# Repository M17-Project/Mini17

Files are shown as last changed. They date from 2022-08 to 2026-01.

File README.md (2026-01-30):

<div align='center'>










</div>

# Mini17
Mini17 - QRP M17 handheld.

# About
The first handheld to suport M17 was our own [TR-9](https://github.com/M17-Project/TR-9). Unfortunately, the design has a minor flaw in the RF part and is very hard to assemble. After that, we tried modifying various radios with different outcomes. This is our new device - the **Mini17**. It's built around the [CC1200](https://www.ti.com/product/CC1200) RF chip, which does great job at receiving and transmitting M17 signals. The power output is limited to 16dBm (40mW), so it's a QRP radio. The idea is to build a small radio first and then add RF power amplifier stage later. A *Proof of Concept*, if you will. The design could even be extended to a mobile rig in the future.

# Hardware
The RF chip used is CC1200, MCU is STM32F405RGT6. OLED display is the same as in [Module17](https://github.com/M17-Project/Module_17).

# Firmware
[OpenRTX](https://github.com/OpenRTX/OpenRTX) - the Linux of amateur radio!

# Structure
`/Hardware/KiCAD` contains two complete KiCAD projects, one for the mainboard and the other for the HMI<br>
`/MCU/Mini17.ioc` contains the pinout plan for an STM32F405RGT6 MCU (to be used with CubeIDE >=1.10.1)

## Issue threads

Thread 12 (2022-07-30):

H* mounting holes

sp5wwp, 2022-07-30:
Size M3 is too big, i suggest M2.

sp5wwp, 2022-07-31:
Fixed.

Closed 2022-07-31.

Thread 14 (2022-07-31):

Microphone-speaker "problem"

sp5wwp, 2022-07-31:
We need a different type of 3.5 and 2.5mm jack connectors to support both internal and external microphone/speaker. See the image below for details (that's a part of TYT MD-380 handheld transceiver).
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

JKI757, 2022-08-07:
Ok here's a 3.5mm that lines up with what you're looking for here I *think*.

https://www.digikey.com/en/products/detail/STX-3200-5NB/2092-STX-3200-5NB-ND/10246571

JKI757, 2022-08-07:
And this looks like a possible for the 2.5mm:

https://www.digikey.ca/en/products/detail/cui-devices/SJ2-25313D-SMT-TR/6619292

JKI757, 2022-08-07:
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

Use this one instead as it's available in lcsc per discussion in chat:

https://www.lcsc.com/product-detail/Audio-Connectors_BOOMELE-Boom-Precision-Elec-PJ-307C_C16684.html

sp5wwp, 2022-08-08:
Schematic fixed.

Closed 2022-08-08.

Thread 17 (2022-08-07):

SD card holder footprint

sp5wwp, 2022-08-07:
Set it to the correct one.

sp5wwp, 2022-08-07:
List:
https://lcsc.com/products/SD-Card-Connectors_11334.html

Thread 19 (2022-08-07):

Missing DFU mode

sp5wwp, 2022-08-07:
Set `BOOTn` pins in the way so that the device enters DFU mode much like the Module17 does - one of the keyboard buttons has to be kept pressed at power-up.

sp5wwp, 2022-08-16:
Added.

Closed 2022-08-16.

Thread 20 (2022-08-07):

Lacking R_EXT for the 8 MHz crystal oscillator

sp5wwp, 2022-08-07:
Add a place for a series resistor at `XTAL_1`, pin #24, make it 0R for now.

Closed 2022-08-07.

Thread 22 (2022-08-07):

Volume potentiometer

sp5wwp, 2022-08-07:
Are we going to use the same pot as in Module17? With an ON/OFF switch.

sp5wwp, 2022-08-08:
Need the PN of the pot used in Module17.

sp5wwp, 2022-08-16:
One of the `ACZ11BRXE` family of pots.

sp5wwp, 2022-08-18:
> This is the potentiometer we used for Module17: https://www.digikey.com/en/products/detail/bourns-inc/PTR901-2015K-B203/3780802

Is the footprint correctly set in the schematic?

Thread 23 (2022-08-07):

Add a rotary encoder with a push button

sp5wwp, 2022-08-07:

JKI757, 2022-08-07:
this one?

https://www.lcsc.com/product-detail/Rotary-Encoders_BOURNS-PEC11R-4015F-S0024_C143789.html

sp5wwp, 2022-08-07:
We need one that's 90*.

JKI757, 2022-08-07:
ah yes, good point.

JKI757, 2022-08-07:
LCSC isn't coming back with something that makes sense at least at first glance, but I did find one at digikey that might work:

https://www.digikey.com/en/products/detail/cts-electrocomponents/11CEY25F243B/13152999

sp5wwp, 2022-08-08:
I believe JLCPCB can source parts from Mouser and Avnet. Lets try there.

Yep:
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

sp5wwp, 2022-08-09:
> LCSC isn't coming back with something that makes sense at least at first glance, but I did find one at digikey that might work:
>
> https://www.digikey.com/en/products/detail/cts-electrocomponents/11CEY25F243B/13152999

I believe this one might be too big to fit between two boards.

sp5wwp, 2022-08-16:
One of the `ACZ11BRXE` family of encoders?

JKI757, 2022-08-17:
This seems to be the only one with the right mounting option available:

https://www.mouser.com/ProductDetail/CUI-Devices/ACZ11BR4E-15FA1-20C?qs=WyjlAZoYn521vRzc3WQA5g%3D%3D

JKI757, 2022-08-17:
ok that's added to the schematic and repo, will be in the PR I send up in a bit.

xfce, 2023-03-07:
hi all
        I am a ham in China, also a hardware engineer and familiar with JLC, my callsign is bi4wms, maybe I can give some help

sp5wwp, 2023-03-07:
Mini17 isn't under development right now, but [OpenHT](https://github.com/M17-Project/OpenHT-hw) is.

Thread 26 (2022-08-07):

RGB LED

sp5wwp, 2022-08-07:
How about using an RGB LED instead of 3 separate ones?

JKI757, 2022-08-07:
I like it.  Nice one shot LED at the top of the radio that can do 4 or 5 different colors without too much trouble would be nice.

sp5wwp, 2022-08-08:
Added in #30

Closed 2022-08-08.

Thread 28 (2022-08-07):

Should we use an open-source alternative to CubeIDE?

uranuspucksaxophone, 2022-08-07:

JKI757, 2022-08-07:
CubeIDE is an ST configured version of Eclipse packaged up with GDB.

CubeMX simply provides configuration info for the MCU.  There's no requirement to use it, and the existing codebases people anticipate putting on here as far as I know aren't based on it. Even if they are, I don't think it matters.

The use of CubeMX/CubeIDE doesn't "infect" anything with regard to licensing, at least not that I'm aware of.

The presence of the .ioc file doesn't place any constraints on anyone -- I'm using CubeMX just a tool to assist in validating schematic design and I'll probably create some test firmware with it at some point as well.  It saves a ton of time in figuring out what pins are compatible with what signals and where to put them for better routing on the PCB as well.

IOW don't read too much into the existence of an ioc file -- it's just a tool.

sp5wwp, 2022-08-07:
This file is only used for setting pin configuration.

Closed 2022-08-07.

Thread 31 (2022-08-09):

Separate boards

sp5wwp, 2022-08-09:
Put all interface (microphone, speaker, keyboard, PTT/F1/F2 buttons, rotary encoder, Kenwood connector, OLED display) on a separate board.

JKI757, 2022-08-10:
Interesting way of looking at it I guess -- was looking at the TYT design, they've got the microphone, keypad, and display on a separate board, but all the other interface components are on the mainboard.

I think we need someone to create a physical design of some sort, because that is going to drive these kinds of discussions.  I was even thinking as I worked on the board tonight, why not just use the tyt front panel as it is?   essentially we'd just be replacing the mainboard, we could even re-use the volume, encoder (which I'm still not finding one that I think will work), PTT buttons, etc.

LongHairedHacker, 2022-08-11:
I don't think creating a replacement mainboard for another device is the best approach here.
It sure is tempting idea you get an enclosure, a battery, display and everything in nice form factor (also chargers and other accessories...)
However I already had some trouble getting a MD380 to mod for M17 for a reasonable price.
So it might not be the best idea to tie peoples ability to build a mini17 to the availability of some existing radio.
Also that doesn't really feel open hardware to me.

In my opinion it might be a little to early to think about physical design.
I'd much rather prefer to to have two stacked rectangular boards in the first iteration.
It shouldn't be to hard to come up with an enclosure for something like that using a lasercutter or a 3d printer.

Once the design verified to work, we can talk designing a nice polished enclosure and make the boards fit in that.

JKI757, 2022-08-11:
You absolutely have to have some physical design to line up your board design to, otherwise you are building a dev board, you might as well totally ignore form factor, and you need to plan to completely redesign it when you decide you want to build a handheld radio -- and there's no point in doing any board at all if you're going to do that, you just buy the manufacturer supplied dev board (https://www.ti.com/tool/CC1200DK) and focus your development efforts on the software.

We've decided to go a different way with this, but MD380s are 130 bucks on Amazon in apparently unlimited quantity, and they're even cheaper used on eBay.  I still think that simply designing a drop-in main board replacement for that radio (or the 390 or any other radio already in the supply chain) would be far superior to other approaches for all the reasons you list above.

sp5wwp, 2022-08-15:
The design is now split into 2.

Closed 2022-08-15.

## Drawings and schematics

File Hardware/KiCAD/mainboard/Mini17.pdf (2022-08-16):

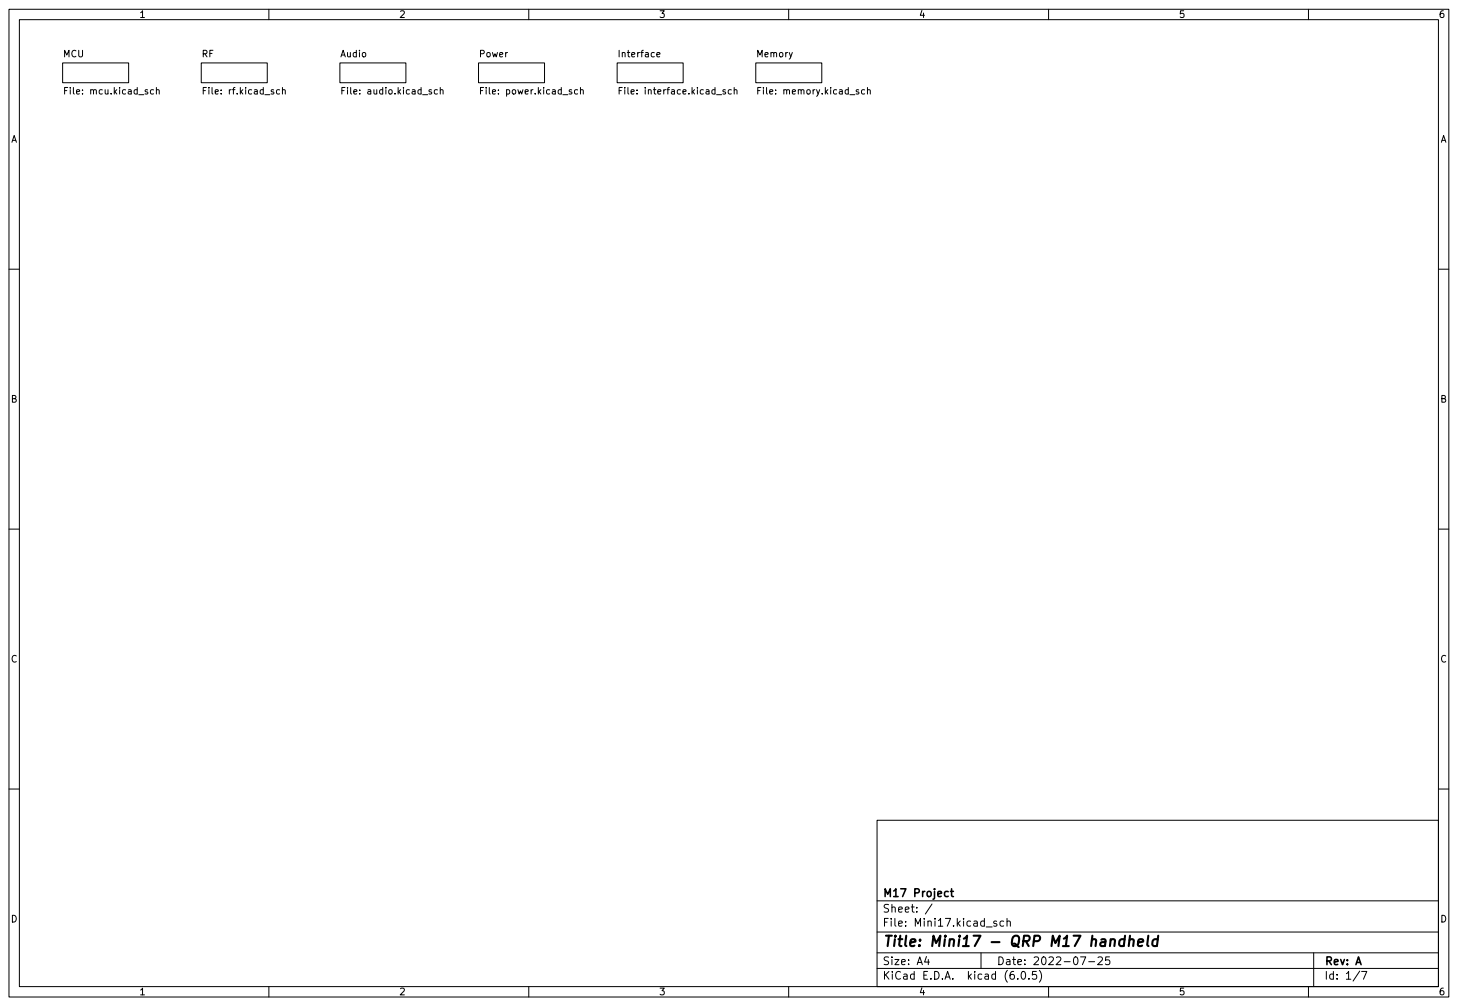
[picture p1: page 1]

Audio File: audio.kicad_sch MCU

Id: 1/7 Title: Mini17 - QRP M17 handheld

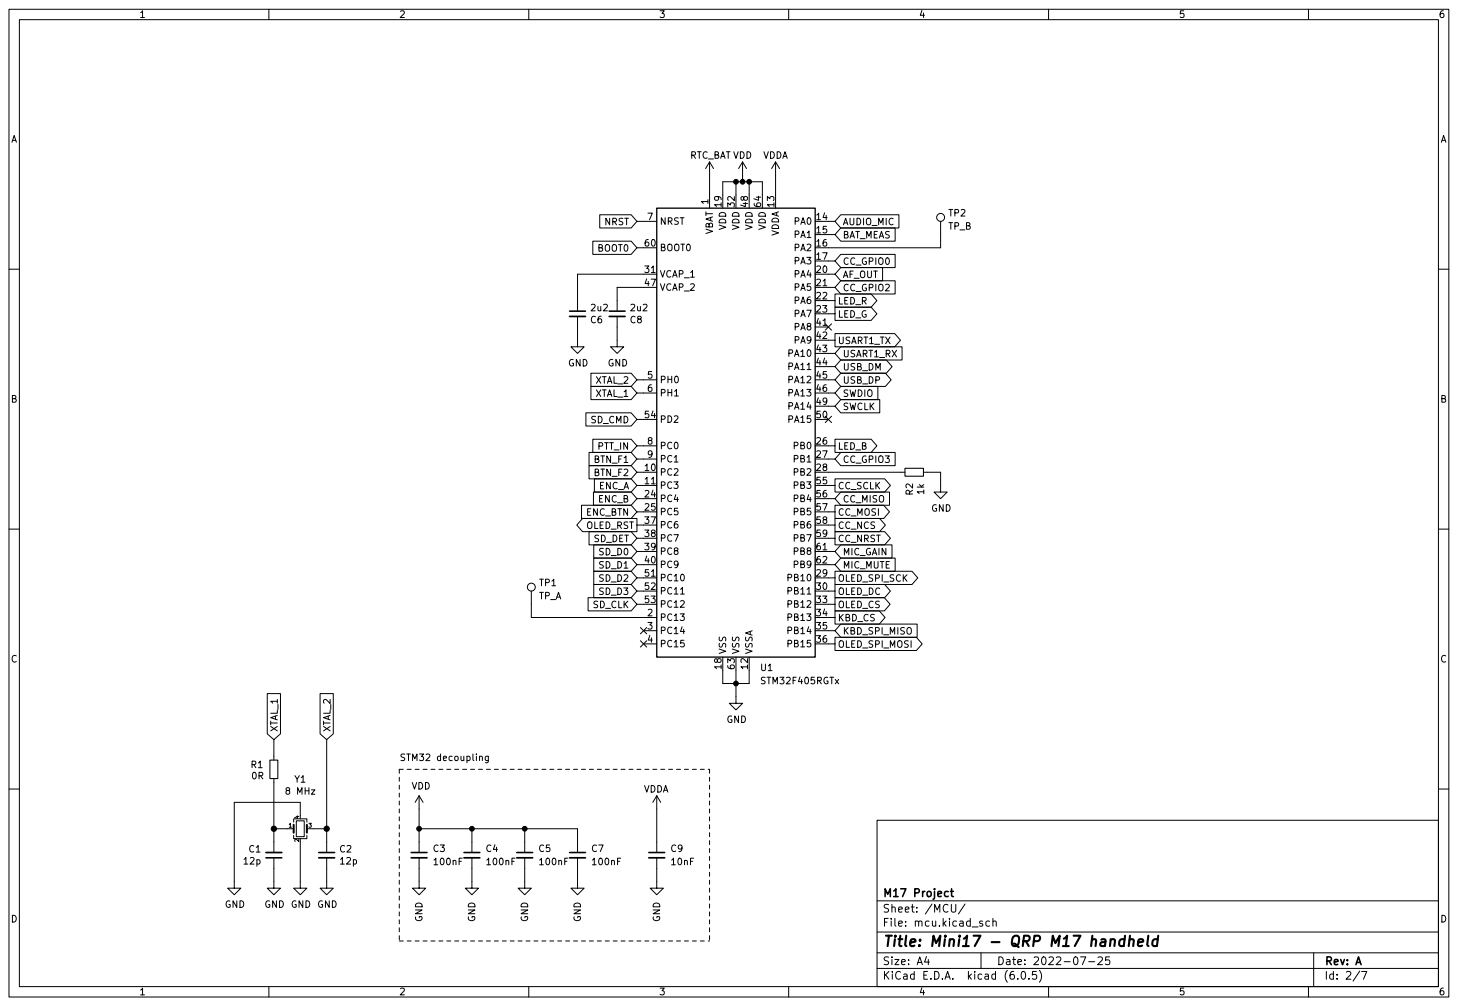
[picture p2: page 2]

File: mcu.kicad_sch Sheet: /MCU/ M17 Project GND

Id: 2/7 Title: Mini17 - QRP M17 handheld

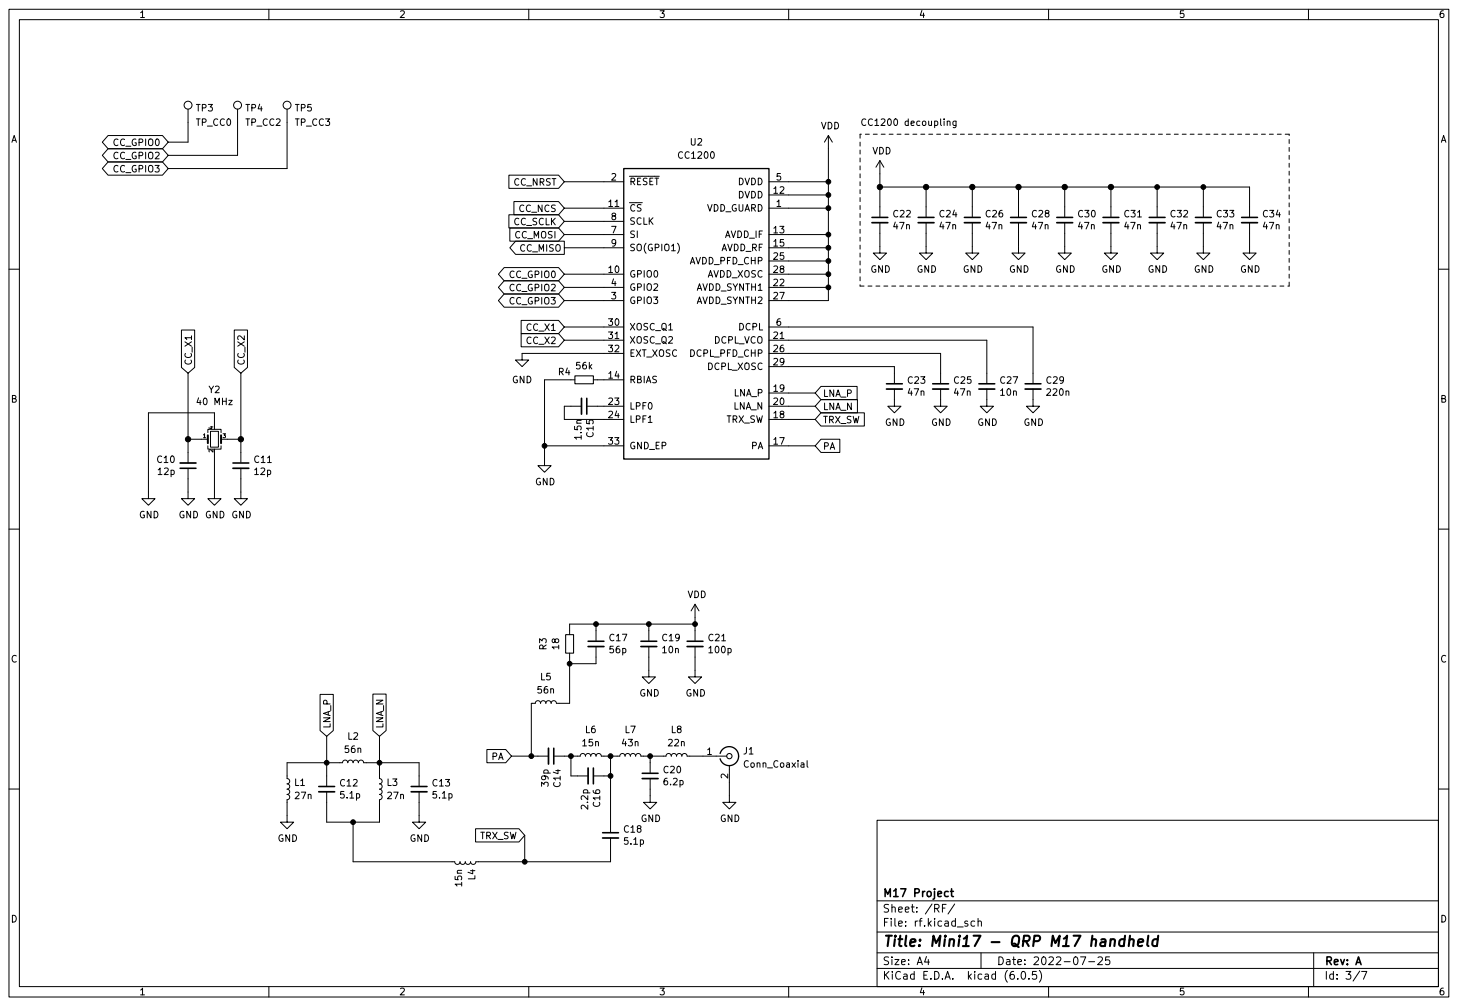
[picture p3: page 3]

Id: 3/7 Title: Mini17 - QRP M17 handheld

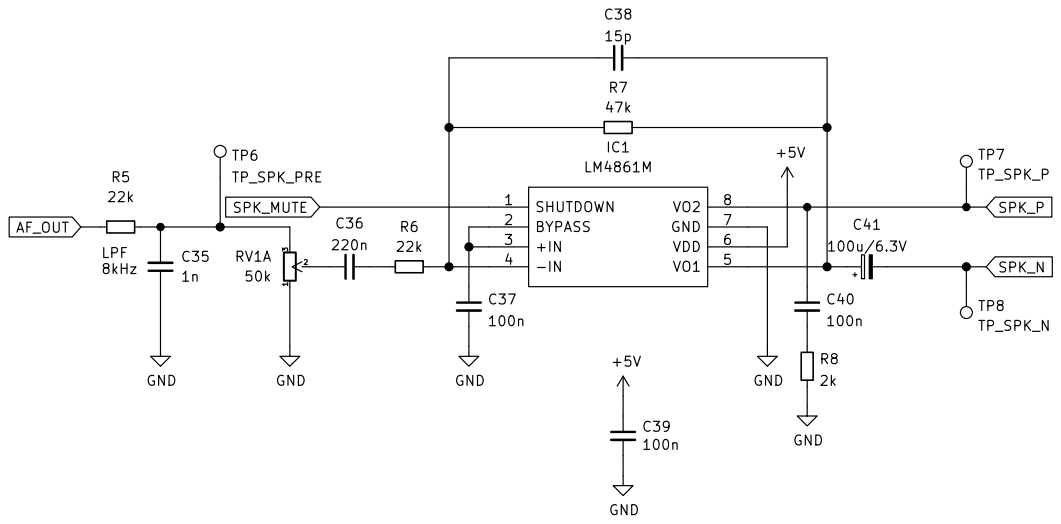
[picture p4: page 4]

File: audio.kicad_sch Sheet: /Audio/ M17 Project

Id: 4/7 Title: Mini17 - QRP M17 handheld

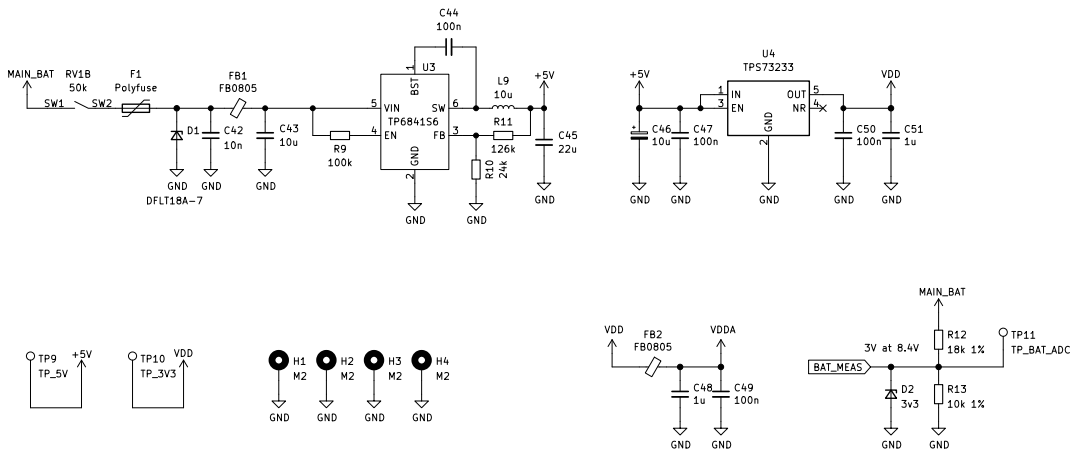
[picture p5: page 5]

2 EN 3 NR 4 OUT 5 U4 TPS73233 H2 M2 GND GND

2 FB 3 EN 4 VIN 5 SW 6 U3 TP6841S6H4 M2 GND

Id: 5/7 Title: Mini17 - QRP M17 handheld

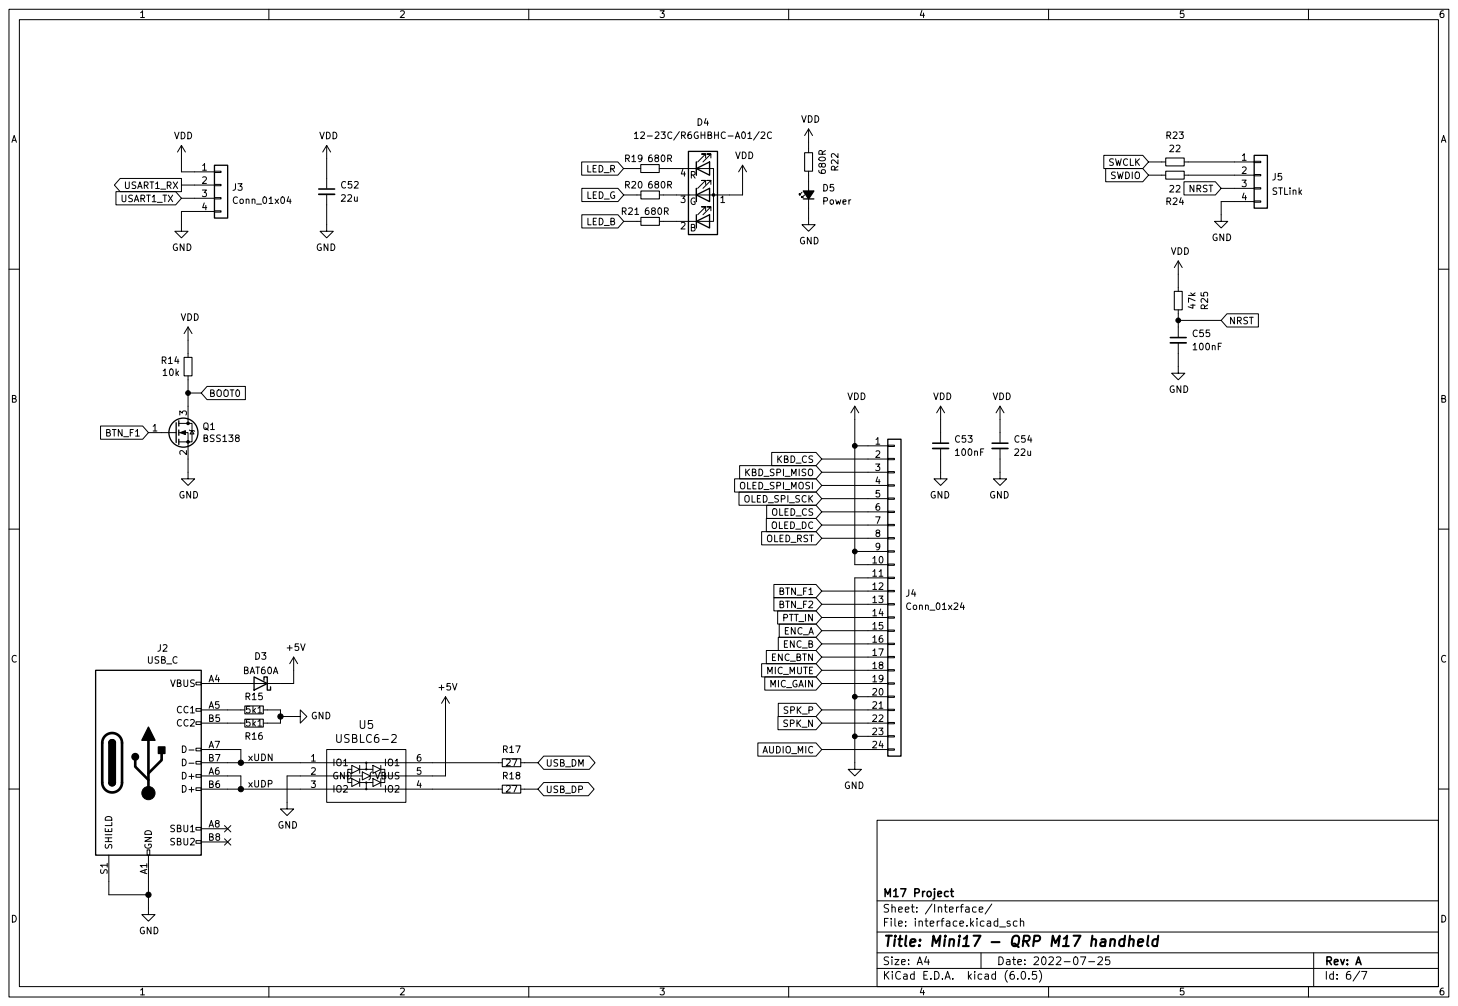
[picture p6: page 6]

File: interface.kicad_sch Sheet: /Interface/ M17 Project GND

Id: 6/7 Title: Mini17 - QRP M17 handheld

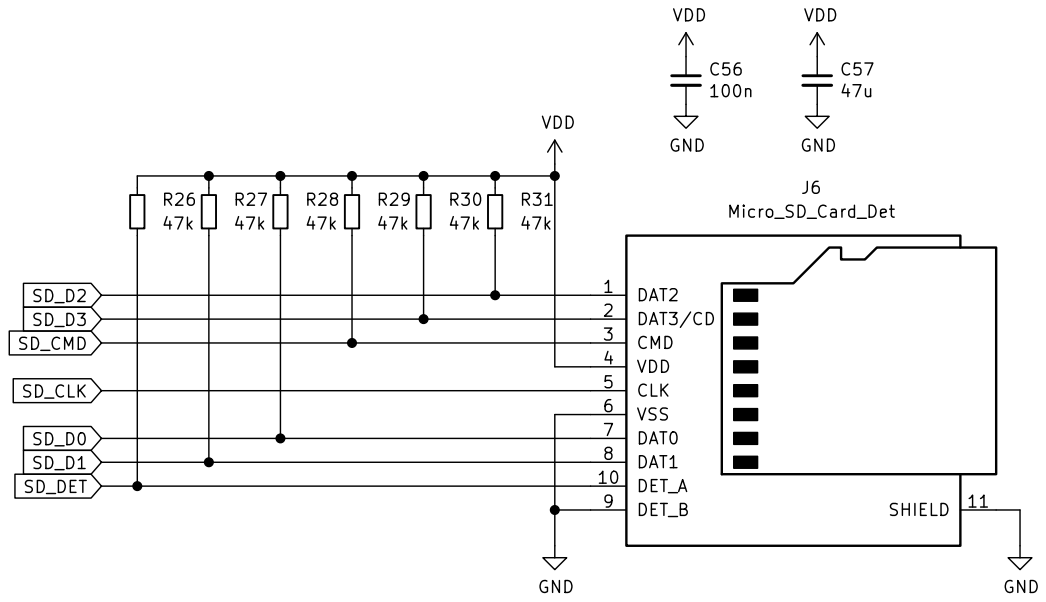
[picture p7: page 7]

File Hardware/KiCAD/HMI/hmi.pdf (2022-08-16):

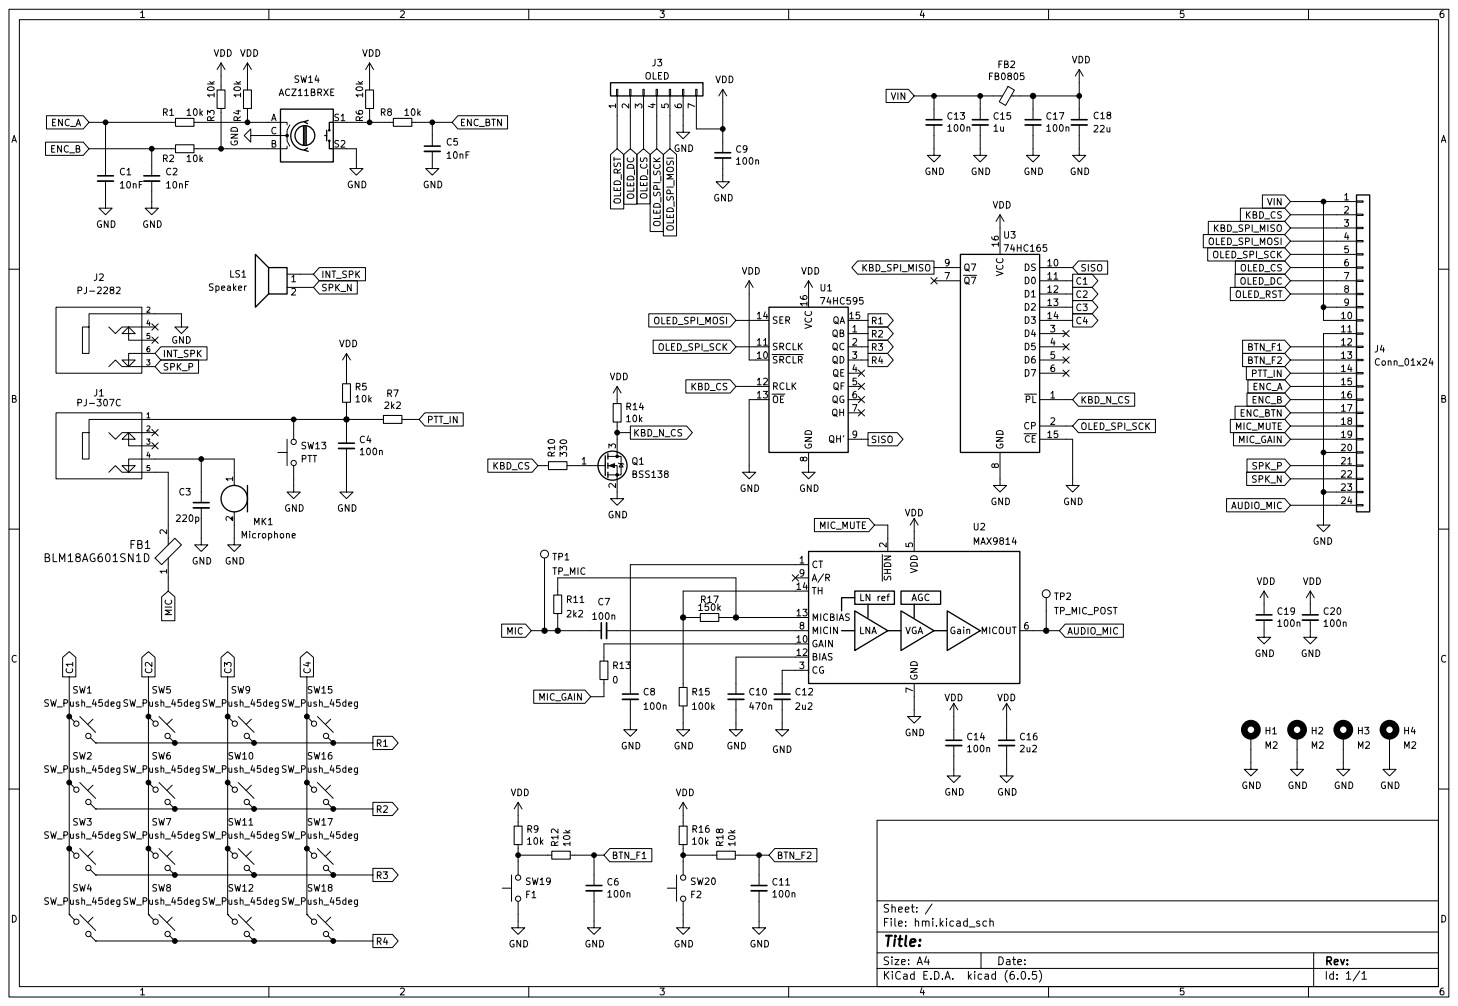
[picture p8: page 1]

7 MICIN 8 A/R 9 U2MAX9814 VDD GND GND GND

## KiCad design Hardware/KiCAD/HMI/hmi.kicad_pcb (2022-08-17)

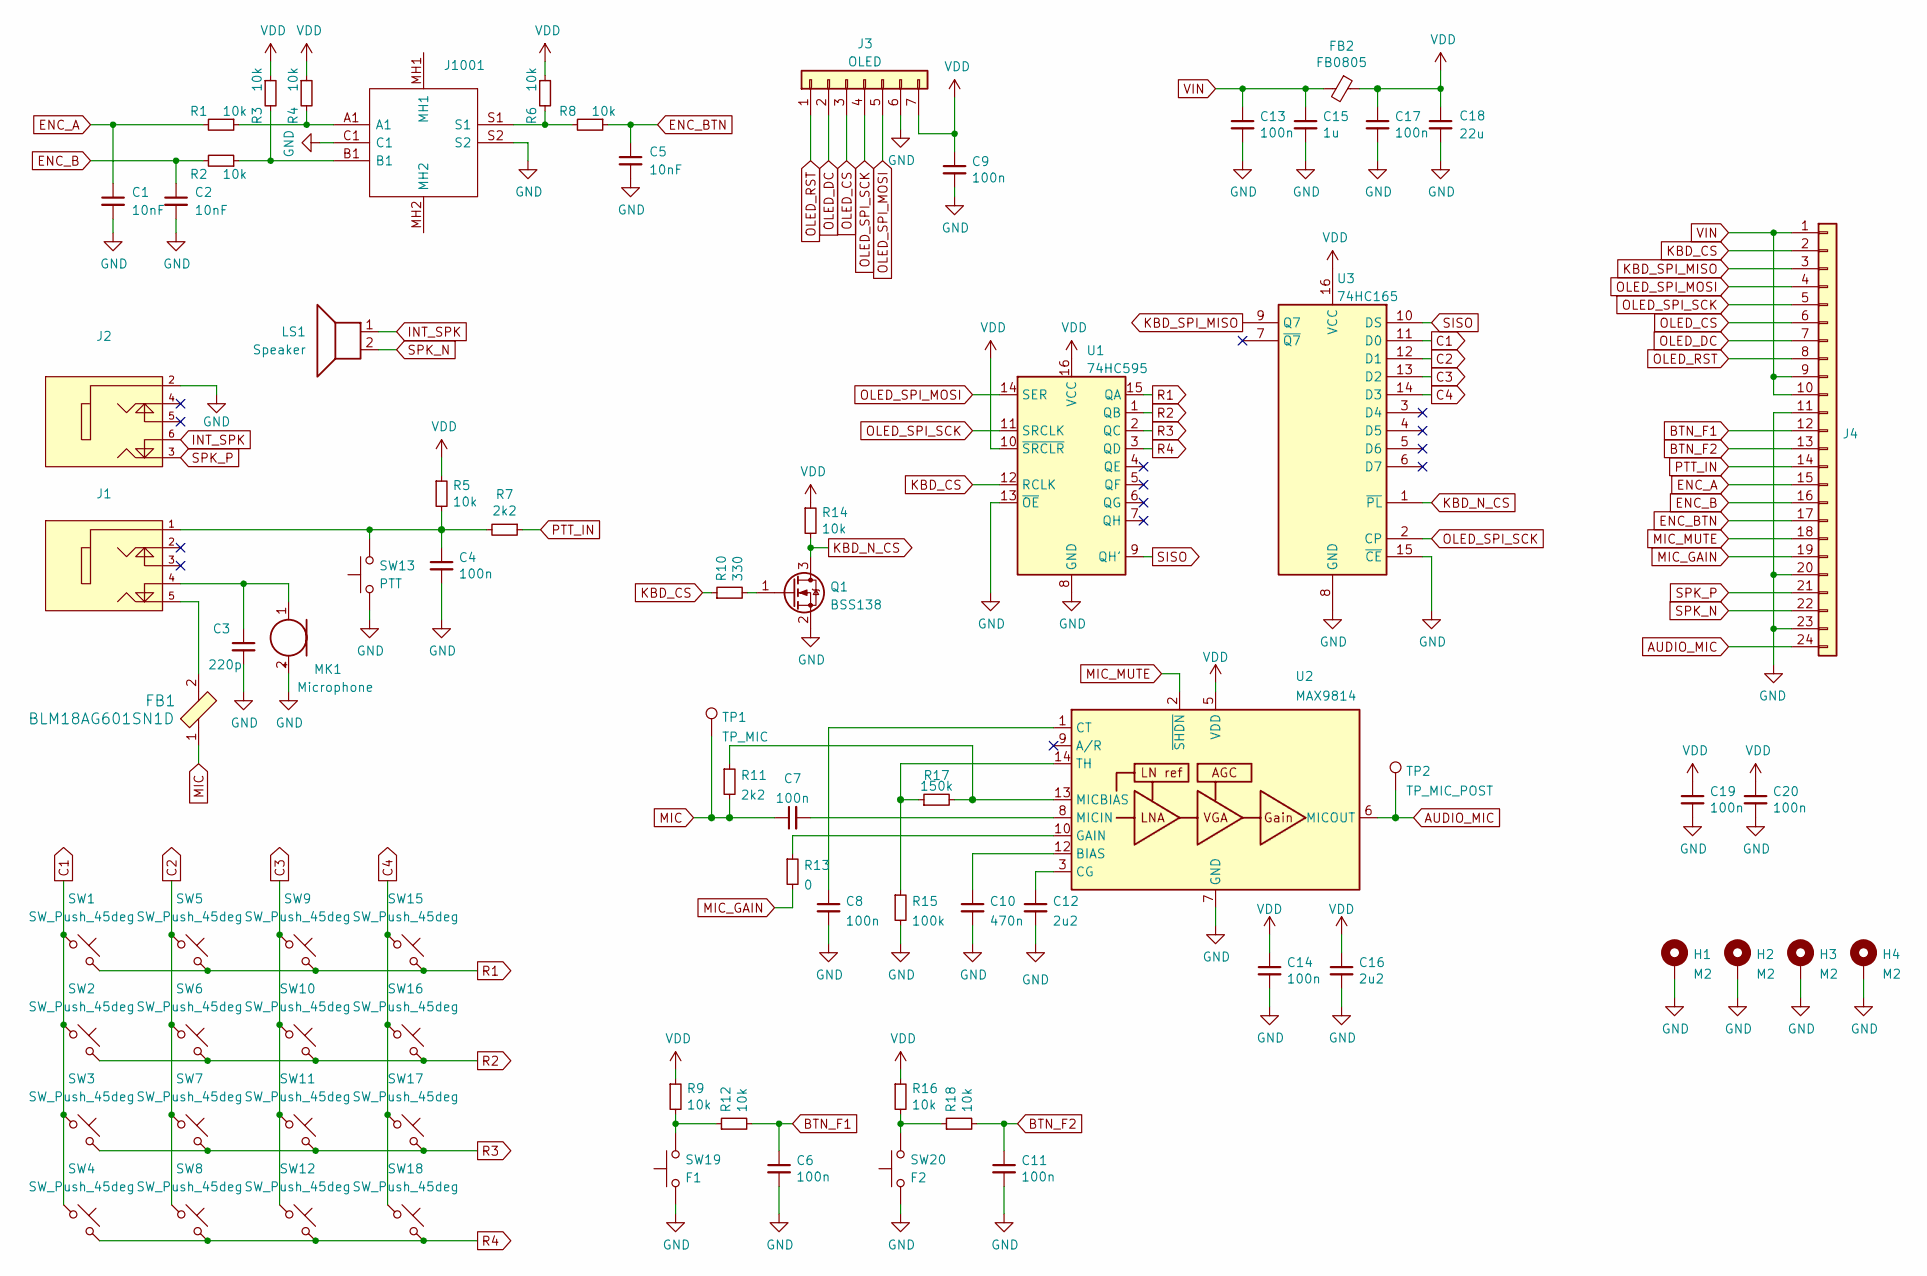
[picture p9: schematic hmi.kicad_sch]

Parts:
C1, C2, C5: 10nF; C_0402_1005Metric
C3: 220p; C_0402_1005Metric
C4, C6, C7, C8, C9, C11, C13, C14, C17, C19, C20: 100n; C_0402_1005Metric
C10: 470n; C_0402_1005Metric
C12, C16: 2u2; C_0402_1005Metric
C15: 1u; C_0402_1005Metric
C18: 22u; C_1210_3225Metric
FB1: BLM18AG601SN1D; 0603; MPN BLM18AG601SN1D; Digi-Key_PN 490-1014-1-ND
FB2: FB0805; Fuse_0805_2012Metric
H1, H2, H3, H4: M2; MountingHole_2.2mm_M2_DIN965_Pad
J1, J2, J4: (no value)
J3: OLED; PinHeader_1x07_P2.54mm_Vertical
J1001: Manufacturer_Part_Number ACZ11BR4E-15FA1-20C; Mouser Part Number 490-ACZ11E15FA120C
LS1: Speaker; PinHeader_1x02_P2.54mm_Vertical
MK1: Microphone
Q1: BSS138; SOT-23
R1, R2, R3, R4, R5, R6, R8, R9, R12, R14, R16, R18: 10k; R_0402_1005Metric
R7, R11: 2k2; R_0402_1005Metric
R10: 330; R_0402_1005Metric
R13: 0; R_0402_1005Metric
R15: 100k; R_0402_1005Metric
R17: 150k; R_0402_1005Metric
SW1, SW2, SW3, SW4, SW5, SW6, SW7, SW8, SW9, SW10, SW11, SW12, SW15, SW16, SW17, SW18: SW_Push_45deg; SW_Push_1P1T_NO_CK_KMR2
SW13: PTT; SW_Tactile_SPST_Angled_PTS645Vx31-2LFS
SW19: F1; SW_Tactile_SPST_Angled_PTS645Vx31-2LFS
SW20: F2; SW_Tactile_SPST_Angled_PTS645Vx31-2LFS
TP1: TP_MIC; TestPoint_Pad_D1.0mm
TP2: TP_MIC_POST; TestPoint_Pad_D1.0mm
U1: 74HC595; SOIC-16_3.9x9.9mm_P1.27mm
U2: MAX9814; DFN-14-1EP_3x3mm_P0.4mm_EP1.78x2.35mm
U3: 74HC165; SOIC-16_3.9x9.9mm_P1.27mm

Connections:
AUDIO_MIC: J4.24, TP2.1, U2.6 (MICOUT)
BTN_F1: C6.1, J4.12, R12.2
BTN_F2: C11.1, J4.13, R18.2
C1: SW1.1, SW2.1, SW3.1, SW4.1, U3.11 (D0)
C2: SW5.1, SW6.1, SW7.1, SW8.1, U3.12 (D1)
C3: SW9.1, SW10.1, SW11.1, SW12.1, U3.13 (D2)
C4: SW15.1, SW16.1, SW17.1, SW18.1, U3.14 (D3)
ENC_A: C1.1, J4.15, R1.2
ENC_B: C2.1, J4.16, R2.2
ENC_BTN: C5.1, J4.17, R8.1
GND: C1.2, C2.2, C3.2, C4.2, C5.2, C6.2, C8.2, C9.2, C10.2, C11.2, C12.2, C13.2, C14.2, C15.2, C16.2, C17.2, C18.2, C19.2, C20.2, H1.1, H2.1, H3.1, H4.1, J2.2, J3.6, J4.11, J4.20, J4.23, J1001.C1, J1001.S2, MK1.2 (+), Q1.2 (S), R15.2, SW13.1, SW19.1, SW20.1, U1.8 (GND), U1.13 (~OE), U2.4 (GND), U2.7 (GND), U2.11 (GND), U2.15 (GND), U3.8 (GND), U3.15 (~CE)
INT_SPK: J2.6, LS1.1
KBD_CS: J4.2, R10.1, U1.12 (RCLK)
KBD_N_CS: Q1.3 (D), R14.2, U3.1 (~PL)
KBD_SPI_MISO: J4.3, U3.9 (Q7)
MIC: C7.1, FB1.1, R11.2, TP1.1
MIC_GAIN: J4.19, R13.2
MIC_MUTE: J4.18, U2.2 (~SHDN)
unnamed: C3.1, J1.4, MK1.1 (-)
unnamed: C4.1, J1.1, R5.2, R7.2, SW13.2
unnamed: C7.2, U2.8 (MICIN)
unnamed: C8.1, U2.1 (CT)
unnamed: C10.1, U2.12 (BIAS)
unnamed: C12.1, U2.3 (CG)
unnamed: FB1.2, J1.5
unnamed: Q1.1 (G), R10.2
unnamed: J1001.A1, R1.1, R4.2
unnamed: J1001.B1, R2.1, R3.2
unnamed: J1001.S1, R6.2, R8.2
unnamed: R11.1, R17.2, U2.13 (MICBIAS)
unnamed: R9.2, R12.1, SW19.2
unnamed: R13.1, U2.10 (GAIN)
unnamed: R15.1, R17.1, U2.14 (TH)
unnamed: R16.2, R18.1, SW20.2
OLED_CS: J3.3, J4.6
OLED_DC: J3.2, J4.7
OLED_RST: J3.1, J4.8
OLED_SPI_MOSI: J3.5, J4.4, U1.14 (SER)
OLED_SPI_SCK: J3.4, J4.5, U1.11 (SRCLK), U3.2 (CP)
PTT_IN: J4.14, R7.1
R1: SW1.2, SW5.2, SW9.2, SW15.2, U1.15 (QA)
R2: SW2.2, SW6.2, SW10.2, SW16.2, U1.1 (QB)
R3: SW3.2, SW7.2, SW11.2, SW17.2, U1.2 (QC)
R4: SW4.2, SW8.2, SW12.2, SW18.2, U1.3 (QD)
SISO: U1.9 (QH'), U3.10 (DS)
SPK_N: J4.22, LS1.2
SPK_P: J2.3, J4.21
VDD: C9.1, C14.1, C16.1, C17.1, C18.1, C19.1, C20.1, FB2.1, J3.7, R3.1, R4.1, R5.1, R6.1, R9.1, R14.1, R16.1, U1.10 (~SRCLR), U1.16 (VCC), U2.5 (VDD), U3.16 (VCC)
VIN: C13.1, C15.1, FB2.2, J4.1, J4.9, J4.10

Board: 2 copper layers, 73 parts (0 on the bottom side), 45 nets, no tracks yet.

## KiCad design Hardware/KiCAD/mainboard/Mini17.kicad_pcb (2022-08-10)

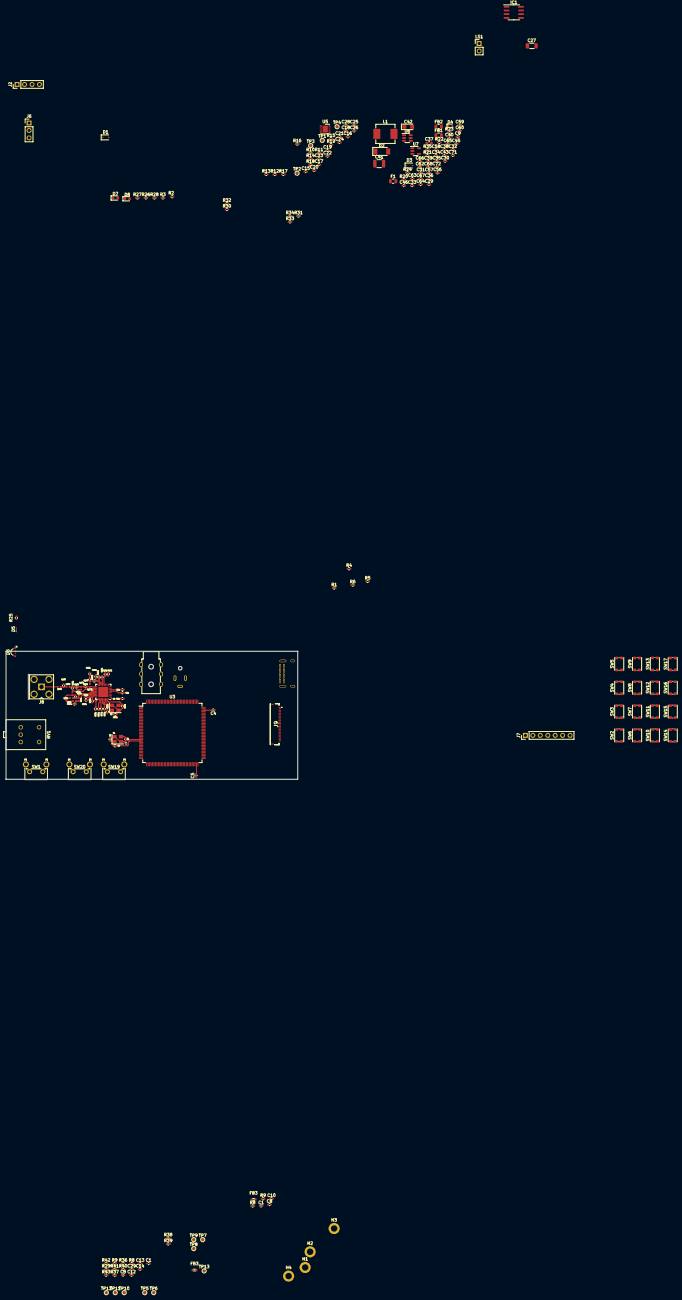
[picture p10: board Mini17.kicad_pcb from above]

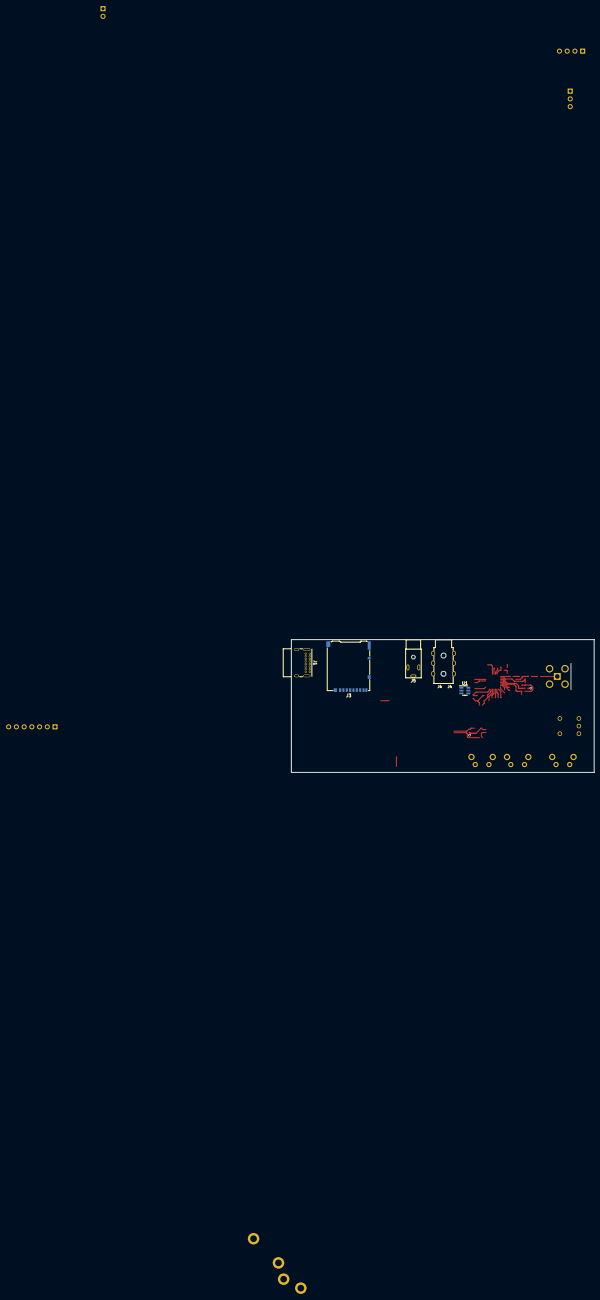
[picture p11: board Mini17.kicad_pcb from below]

Board: 4 copper layers, 99.6 x 43.7 mm, 209 parts (5 on the bottom side), 123 nets.

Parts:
C1, C23, C61: 220n; C_0402_1005Metric
C1#2, C8#2, C12, C68: 10nF; C_0402_1005Metric
C2, C3, C301, C311: 12p; C_0402_1005Metric
C4, C5, C19, C21: 2u2; C_0402_1005Metric
C8: 4.7u; C_0402_1005Metric
C9, C13, C56, C57, C58, C59, C60, C62, C63, C64, C65, C66, C67: 100nF; C_0402_1005Metric
C10: 220p; C_0402_1005Metric
C11, C29#2, C30, C31, C32, C33, C34, C36, C51, C71, C72, C121, C131, C151, C221, C251, C261, C271, C281, C291: 47n; C_0402_1005Metric
C14, C15, C16, C18, C20, C24, C26, C28, C29, C38, C40, C43, C45: 100n; C_0402_1005Metric
C17: 470n; C_0402_1005Metric
C22: 1n; C_0402_1005Metric
C25: 15p; C_0402_1005Metric
C27: 100u/6.3V; C_1206_3216Metric
C35, C171, C211: 10n; C_0402_1005Metric
C37: 10u; C_0603_1608Metric
C39, C46: 1u; C_0402_1005Metric
C41: 22u; C_1210_3225Metric
C42: 10u; CP_EIA-3216-18_Kemet-A
C172: 100p; C_0402_1005Metric
C173: 56p; C_0402_1005Metric
C174: 39p; C_0402_1005Metric
C175: 6.2p; C_0402_1005Metric
C176: 2.2p; C_0402_1005Metric
C181, C191, C201: 5.1p; C_0402_1005Metric
C231: 1.5n; C_0402_1005Metric
D1, D3: BAT60A; D_SOD-323
D2: DFLT18A-7; D_SOD-128
D4: 3v3; D_SOD-523
D5: Power; D_0201_0603Metric
D6: 12-23C/R6GHBHC-A01/2C; LED_RGB_Everlight_EASV3015RGBA0_Horizontal
D7: Sync; D_0603_1608Metric
D8: Error; D_0603_1608Metric
F1: Polyfuse; Fuse_0805_2012Metric
FB1, FB2: FB0805; Fuse_0805_2012Metric
FB3, FB3#2: BLM18AG601SN1D; 0603
H1, H2, H3, H4: M2; MountingHole_2.2mm_M2_DIN965_Pad
IC1: LM4861M; SOIC-8_3.9x4.9mm_P1.27mm
J1: USB_C; USB_C_Receptacle_GCT_USB4085
J2: STLink; PinHeader_1x04_P2.54mm_Vertical
J3: Micro_SD_Card_Det; microSD_HC_Hirose_DM3AT-SF-PEJM5
J4: Kenwood-3.5; PJ-3136-B
J5: Kenwood-2.5; PJ-211A
J6: UART; PinHeader_1x03_P2.54mm_Vertical
J7: OLED; PinHeader_1x07_P2.54mm_Vertical
J8: Conn_Coaxial; SMA_Amphenol_901-143_Horizontal
J9: Front Panel Connector; FH19SC24S05SH09
L1: 10u; L_Vishay_IHLP-2525
L171, L191: 56n; L_0402_1005Metric
L172, L193: 15n; L_0402_1005Metric
L173: 43n; L_0402_1005Metric
L174: 22n; L_0402_1005Metric
L192, L201: 27n; L_0402_1005Metric
LS1: Speaker; PinHeader_1x02_P2.54mm_Vertical
R1, R2: 5k1; R_0402_1005Metric
R3, R4: 22; R_0402_1005Metric
R5, R6: 27; R_0402_1005Metric
R7: 0R; R_0402_1005Metric
R8, R9#2, R14, R29, R36, R37, R38, R40, R41, R42, R43: 10k; R_0402_1005Metric
R8#2: 470; R_0402_1005Metric
R9: 1k8; R_0402_1005Metric
R10, R15: 2k2; R_0402_1005Metric
R11: 0; R_0402_1005Metric
R12, R20: 100k; R_0402_1005Metric
R13: 150k; R_0402_1005Metric
R16, R17: 22k; R_0402_1005Metric
R18, R30, R31, R32, R33, R34, R39: 47k; R_0402_1005Metric
R19: 2k; R_0402_1005Metric
R21: 24k; R_0402_1005Metric
R22: 126k; R_0402_1005Metric
R23: 18k 1%; R_0402_1005Metric
R24: 10k 1%; R_0402_1005Metric
R25, R26, R27, R28: 680R; R_0402_1005Metric
R35: 1k; R_0402_1005Metric
R141: 56k; R_0402_1005Metric
R171: 18; R_0402_1005Metric
RV1: 50k; PTR901
SW1: PTT; SW_Tactile_SPST_Angled_PTS645Vx31-2LFS
SW2, SW3, SW4, SW5, SW6, SW7, SW8, SW9, SW10, SW11, SW12, SW13, SW14, SW15, SW16, SW17: SW_Push_45deg; SW_Push_1P1T_NO_CK_KMR2
SW19: F1; SW_Tactile_SPST_Angled_PTS645Vx31-2LFS
SW20: F2; SW_Tactile_SPST_Angled_PTS645Vx31-2LFS
TP1: TP_MIC; TestPoint_Pad_D1.0mm
TP2: TP_MIC_POST; TestPoint_Pad_D1.0mm
TP3: TP_SPK_PRE; TestPoint_Pad_D1.0mm
TP4: TP_SPK_N; TestPoint_Pad_D1.0mm
TP5: TP_B; TestPoint_Pad_D1.0mm
TP6: TP_A; TestPoint_Pad_D1.0mm
TP7: TP_CC0; TestPoint_Pad_D1.0mm
TP8: TP_CC2; TestPoint_Pad_D1.0mm
TP9: TP_CC3; TestPoint_Pad_D1.0mm
TP10: TP_5V; TestPoint_Pad_D1.0mm
TP11: TP_3V3; TestPoint_Pad_D1.0mm
TP12: TP_BAT_ADC; TestPoint_Pad_D1.0mm
TP13: TP_SPK_P; TestPoint_Pad_D1.0mm
U1: USBLC6-2; SOT-23-6
U3: STM32F427ZGTx; LQFP-144_20x20mm_P0.5mm
U4: CC1200; QFN-32-1EP_5x5mm_P0.5mm_EP3.45x3.45mm
U5: MAX9814; DFN-14-1EP_3x3mm_P0.4mm_EP1.78x2.35mm
U6: TP6841S6; SOT-23-6
U7: TPS73233; SOT-23-5
Y1: 8 MHz; Crystal_SMD_3225-4Pin_3.2x2.5mm
Y3: 40 MHz; Crystal_SMD_3225-4Pin_3.2x2.5mm

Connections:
+5V: C28.1, C41.1, C42.1, C43.1, D1.1 (K), IC1.6 (VDD), J4.T, L1.1, R8#2.1, R22.2, TP10.1, U1.5 (VBUS), U7.1 (IN), U7.3 (EN)
/Interface/xUDN: J1.A7 (D-), J1.B7 (D-), U1.1 (IO1)
/Interface/xUDP: J1.A6 (D+), J1.B6 (D+), U1.3 (IO2)
AF_OUT: R16.1, U3.40 (PA4)
AUDIO_MIC: TP2.1, U3.34 (PA0), U5.6 (MICOUT)
BAT_MEAS: D4.1 (K), R23.2, R24.1, TP12.1, U3.35 (PA1)
BOOT0: C29.1, R43.2, U3.22 (PF10), U3.138 (BOOT0)
BTN_F1: C14.1, R41.2, U3.26 (PC0)
C1: J9.5, SW2.1, SW3.1, SW4.1, SW5.1, U3.57 (PG1)
C2: J9.4, SW6.1, SW7.1, SW8.1, SW9.1, U3.58 (PE7)
C3: J9.3, SW10.1, SW11.1, SW12.1, SW13.1, U3.59 (PE8)
C4: J9.2, SW14.1, SW15.1, SW16.1, SW17.1, U3.60 (PE9)
CC_GPIO0: TP7.1, U3.129 (PG14), U4.10 (GPIO0)
CC_GPIO2: TP8.1, U3.128 (PG13), U4.4 (GPIO2)
CC_GPIO3: TP9.1, U3.127 (PG12), U4.3 (GPIO3)
CC_MISO: U3.20 (PF8), U4.9 (SO(GPIO1))
CC_MOSI: U3.21 (PF9), U4.7 (SI)
CC_NCS: U3.18 (PF6), U4.11 (~CS)
CC_NRST: U3.15 (PF5), U4.2 (~RESET)
CC_SCLK: U3.19 (PF7), U4.8 (SCLK)
CC_X1: C301.2, U4.30 (XOSC_Q1), Y3.1
CC_X2: C311.1, U4.31 (XOSC_Q2), Y3.3
ENC_A: C1#2.1, R8.2, U3.97 (PC7)
ENC_B: C8#2.1, R9#2.2, U3.96 (PC6)
ENC_BTN: C12.1, R38.1, U3.93 (PG8)
GND: C1.2, C1#2.2, C2.1, C3.2, C4.1, C5.1, C8.2, C8#2.2, C9.2, C10.2, C11.2, C12.2, C13.2, C14.2, C16.2, C17.2, C18.2, C19.2, C20.2, C21.2, C22.1, C24.2, C28.2, C29.2, C29#2.2, C30.2, C31.2, C32.2, C33.2, C34.2, C35.1, C36.2, C37.2, C39.2, C40.2, C41.2, C42.2, C43.2, C45.2, C46.2, C51.2, C56.2, C57.2, C58.2, C59.2, C60.2, C61.2, C62.2, C63.2, C64.2, C65.2, C66.2, C67.2, C68.2, C71.2, C72.2, C121.2, C131.2, C151.2, C171.2, C172.2, C175.2, C201.2, C211.2, C221.2, C251.2, C261.2, C271.2, C281.2, C291.2, C301.1, C311.2, D2.2 (A), D4.2 (A), D5.1 (K), H1.1, H2.1, H3.1, H4.1, IC1.7 (GND), J1.A1 (GND), J1.A12 (GND), J1.B1 (GND), J1.B12 (GND), J1.S1 (SHIELD), J3.6 (VSS), J3.9 (DET_B), J3.11 (SHIELD), J5.R, J5.S, J6.3, J7.6, J8.2 (Ext), J9.24, L192.2, R1.1, R2.1, R12.2, R19.2, R21.1, R24.2, R141.2, RV1.1, SW1.1, SW19.1, SW20.1, U1.2 (GND), U3.16 (VSS), U3.31 (VSSA), U3.38 (VSS), U3.51 (VSS), U3.61 (VSS), U3.83 (VSS), U3.94 (VSS), U3.107 (VSS), U3.120 (VSS), U3.130 (VSS), U4.32 (EXT_XOSC), U4.33 (GND_EP), U5.4 (GND), U5.7 (GND), U5.11 (GND), U5.15 (GND), U6.2 (GND), U7.2 (GND), Y1.2, Y1.4, Y3.2, Y3.4
LNA_N: C201.1, L191.2, L201.1, U4.20 (LNA_N)
LNA_P: C191.1, L191.1, L192.1, U4.19 (LNA_P)
MIC: C15.1, FB3#2.1, J4.R, R10.2, TP1.1
MIC_GAIN: R11.2, U3.28 (PC2)
MIC_MUTE: U3.29 (PC3), U5.2 (~SHDN)
NRST: C13.1, J2.3, R39.1, U3.25 (NRST)
unnamed: C1.1, C8.1, R8#2.2, R9.1
unnamed: C2.2, R7.2, Y1.1
unnamed: C4.2, U3.106 (VCAP_2)
unnamed: C5.2, U3.71 (VCAP_1)
unnamed: C10.1, FB3.1, FB3.2, R9.2
unnamed: C15.2, U5.8 (MICIN)
unnamed: C16.1, U5.1 (CT)
unnamed: C17.1, U5.12 (BIAS)
unnamed: C18.1, J4.S, R14.2, R15.2, SW1.2
unnamed: C19.1, U5.3 (CG)
unnamed: C22.2, R16.2, RV1.3, TP3.1
unnamed: C23.1, RV1.2
unnamed: C23.2, R17.1
unnamed: C24.1, IC1.2 (BYPASS), IC1.3 (+IN)
unnamed: C25.1, IC1.4 (-IN), R17.2, R18.1
unnamed: C25.2, C27.1, IC1.5 (VO1), R18.2
unnamed: C26.2, R19.1
unnamed: C35.2, D2.1 (K), F1.2, FB1.2
unnamed: C37.1, FB1.1, R20.1, U6.5 (VIN)
unnamed: C38.1, U6.1 (BST)
unnamed: C38.2, L1.2, U6.6 (SW)
unnamed: C61.1, U4.6 (DCPL)
unnamed: C173.2, L171.2, R171.2
unnamed: C174.1, C176.2, L172.1
unnamed: C175.1, L173.2, L174.1
unnamed: C176.1, C181.1, L172.2, L173.1
unnamed: C191.2, L193.2, L201.2
unnamed: C211.1, U4.21 (DCPL_VCO)
unnamed: C231.1, U4.23 (LPF0)
unnamed: C231.2, U4.24 (LPF1)
unnamed: C261.1, U4.26 (DCPL_PFD_CHP)
unnamed: C291.1, U4.29 (DCPL_XOSC)
unnamed: D1.2 (A), J1.A4 (VBUS), J1.A9 (VBUS), J1.B4 (VBUS), J1.B9 (VBUS)
unnamed: D3.1 (K), R35.2
unnamed: D5.2 (A), R25.1
unnamed: D6.2 (BK), R28.1
unnamed: D6.3 (GK), R27.1
unnamed: D6.4 (RK), R26.1
unnamed: F1.1, RV1.SW2 (SW)
unnamed: J1.A5 (CC1), R1.2
unnamed: J1.B5 (CC2), R2.2
unnamed: J2.1, R3.2
unnamed: J2.2, R4.2
unnamed: J8.1 (In), L174.2
unnamed: R5.1, U1.6 (IO1)
unnamed: R6.1, U1.4 (IO2)
unnamed: R10.1, R13.2, U5.13 (MICBIAS)
unnamed: R11.1, U5.10 (GAIN)
unnamed: R12.1, R13.1, U5.14 (TH)
unnamed: R20.2, U6.4 (EN)
unnamed: R21.2, R22.1, U6.3 (FB)
unnamed: R9#2.1, R29.2
unnamed: R8.1, R36.2
unnamed: R37.2, R38.2
unnamed: R40.2, R41.1, SW19.2
unnamed: R42.2, R43.1, SW20.2
unnamed: R141.1, U4.14 (RBIAS)
unnamed: TP5.1, U3.142 (PE1)
unnamed: TP6.1, U3.141 (PE0)
OLED_CS: J7.3, J9.12, U3.73 (PB12)
OLED_DC: J7.2, J9.13, U3.70 (PB11)
OLED_RST: J7.1, J9.14, U3.74 (PB13)
OLED_SPI_MOSI: J7.5, J9.10, U3.76 (PB15)
OLED_SPI_SCK: J7.4, J9.11, U3.69 (PB10)
PA: C174.2, L171.1, U4.17 (PA)
PTT_IN: R15.1, U3.27 (PC1)
R1: J9.9, SW2.2, SW6.2, SW10.2, SW14.2, U3.56 (PG0)
R2: J9.8, SW3.2, SW7.2, SW11.2, SW15.2, U3.55 (PF15)
R3: J9.7, SW4.2, SW8.2, SW12.2, SW16.2, U3.54 (PF14)
R4: J9.6, SW5.2, SW9.2, SW13.2, SW17.2, U3.53 (PF13)
SD_CLK: J3.5 (CLK), U3.113 (PC12)
SD_CMD: J3.3 (CMD), R32.2, U3.116 (PD2)
SD_D0: J3.7 (DAT0), R31.2, U3.98 (PC8)
SD_D1: J3.8 (DAT1), R30.2, U3.99 (PC9)
SD_D2: J3.1 (DAT2), R34.2, U3.111 (PC10)
SD_D3: J3.2 (DAT3/CD), R33.2, U3.112 (PC11)
SD_DET: J3.10 (DET_A), U3.114 (PD0)
SPK_N: C27.2, LS1.2, TP4.1
SPK_P: C26.1, IC1.8 (VO2), TP13.1
SWCLK: R3.1, U3.109 (PA14)
SWDIO: R4.1, U3.105 (PA13)
TRX_SW: C181.2, L193.1, U4.18 (TRX_SW)
USART1_RX: J6.1, U3.102 (PA10)
USART1_TX: J6.2, U3.101 (PA9)
USB_DM: R5.2, U3.103 (PA11)
USB_DP: R6.2, U3.104 (PA12)
VBAT: R23.1, R35.1, RV1.SW1 (SW), U3.6 (VBAT)
VDD: C9.1, C11.1, C20.1, C21.1, C29#2.1, C30.1, C31.1, C32.1, C33.1, C34.1, C36.1, C45.1, C46.1, C51.1, C56.1, C57.1, C58.1, C59.1, C60.1, C62.1, C63.1, C64.1, C65.1, C66.1, C67.1, C71.1, C72.1, C121.1, C131.1, C151.1, C171.1, C172.1, C173.1, C221.1, C251.1, C271.1, C281.1, D3.2 (A), D6.1 (A), FB2.2, J3.4 (VDD), J7.7, J9.1, R14.1, R25.2, R29.1, R30.1, R31.1, R32.1, R33.1, R34.1, R36.1, R37.1, R40.1, R42.1, R171.1, TP11.1, U3.17 (VDD), U3.30 (VDD), U3.39 (VDD), U3.52 (VDD), U3.62 (VDD), U3.72 (VDD), U3.84 (VDD), U3.95 (VDD), U3.108 (VDD), U3.121 (VDD), U3.131 (VDD), U3.144 (VDD), U4.1 (VDD_GUARD), U4.5 (DVDD), U4.12 (DVDD), U4.13 (AVDD_IF), U4.15 (AVDD_RF), U4.22 (AVDD_SYNTH1), U4.25 (AVDD_PFD_CHP), U4.27 (AVDD_SYNTH2), U4.28 (AVDD_XOSC), U5.5 (VDD), U7.5 (OUT)
VDDA: C39.1, C40.1, C68.1, FB2.1, U3.32 (VREF+), U3.33 (VDDA)
XTAL_1: R7.1, U3.24 (PH1)
XTAL_2: C3.1, U3.23 (PH0), Y1.3

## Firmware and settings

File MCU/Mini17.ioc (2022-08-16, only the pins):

Mcu.UserName=STM32F405RGTx
PA0-WKUP.GPIO_Label=AUDIO_MIC
PA0-WKUP.Signal=ADCx_IN0
PA1.GPIO_Label=BAT_MEAS
PA1.Signal=ADCx_IN1
PA10.Signal=USART1_RX
PA11.Signal=USB_OTG_FS_DM
PA12.Signal=USB_OTG_FS_DP
PA13.Signal=SYS_JTMS-SWDIO
PA14.Signal=SYS_JTCK-SWCLK
PA2.GPIO_Label=TP_B
PA2.Signal=GPIO_Output
PA3.GPIO_Label=CC_GPIO0
PA3.Signal=GPIO_Input
PA4.GPIO_Label=AF_OUT
PA4.Signal=COMP_DAC1_group
PA5.GPIO_Label=CC_GPIO2
PA5.Signal=GPIO_Input
PA6.GPIO_Label=LED_R
PA6.Signal=S_TIM3_CH1
PA7.GPIO_Label=LED_G
PA7.Signal=S_TIM3_CH2
PA9.Signal=USART1_TX
PB0.GPIO_Label=LED_B
PB0.Signal=S_TIM3_CH3
PB1.GPIO_Label=CC_GPIO3
PB1.Signal=GPIO_Input
PB10.Signal=SPI2_SCK
PB11.GPIO_Label=OLED_DC
PB11.Signal=GPIO_Output
PB12.GPIO_Label=OLED_CS
PB12.Signal=GPIO_Output
PB13.GPIO_Label=KBD_CS
PB13.Signal=GPIO_Output
PB14.Signal=SPI2_MISO
PB15.Signal=SPI2_MOSI
PB3.Signal=SPI1_SCK
PB4.Signal=SPI1_MISO
PB5.Signal=SPI1_MOSI
PB6.GPIO_Label=SPI1_CS
PB6.Signal=GPIO_Output
PB7.GPIO_Label=SPI1_RST
PB7.Signal=GPIO_Output
PB8.GPIO_Label=MIC_GAIN
PB8.Signal=GPIO_Output
PB9.GPIO_Label=MIC_MUTE
PB9.Signal=GPIO_Output
PC0.GPIO_Label=PTT_IN
PC0.Signal=GPXTI0
PC1.GPIO_Label=BTN_F1
PC1.Signal=GPXTI1
PC10.Signal=SDIO_D2
PC11.Signal=SDIO_D3
PC12.Signal=SDIO_CK
PC13-ANTI_TAMP.GPIO_Label=TP_A
PC13-ANTI_TAMP.Signal=GPIO_Output
PC2.GPIO_Label=BTN_F2
PC2.Signal=GPXTI2
PC3.GPIO_Label=ENC_A
PC3.Signal=GPXTI3
PC4.GPIO_Label=ENC_B
PC4.Signal=GPXTI4
PC5.GPIO_Label=ENC_BTN
PC5.Signal=GPXTI5
PC6.GPIO_Label=OLED_RST
PC6.Signal=GPIO_Output
PC7.GPIO_Label=SD_DET
PC7.Signal=GPXTI7
PC8.Signal=SDIO_D0
PC9.Signal=SDIO_D1
PD2.Signal=SDIO_CMD
PH0-OSC_IN.Signal=RCC_OSC_IN
PH1-OSC_OUT.Signal=RCC_OSC_OUT

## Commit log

2022-07-27 RF part update
    [Mini17.kicad_sch, audio.kicad_sch, interface.kicad_sch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]
2022-07-27 Organize schematics into folders V2
    [Mini17.kicad_pcb, Mini17.kicad_sch, audio.kicad_sch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]
2022-07-27 Add 4x4 keyboard
    [Mini17.kicad_sch, interface.kicad_sch]
2022-07-29 Add decoupling capacitors and fix issue #7
    [Mini17.kicad_sch, interface.kicad_sch, mcu.kicad_sch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]
2022-07-29 Added footprints for decoupling caps
    [Mini17.kicad_sch, audio.kicad_sch, mcu.kicad_sch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]
2022-07-31 Connected SD card to the micro
    [Mini17.kicad_sch, interface.kicad_sch, mcu.kicad_sch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]
2022-07-31 Update
    - `H*` holes changed to M2
    - RTC battery was connected to `VDDA` instead of `VDD`
    - added CC1200 decoupling caps
    [Mini17.kicad_sch, power.kicad_sch]
2022-07-31 Added some connections
    [audio.kicad_sch, mcu.kicad_sch, rf.kicad_sch]
2022-08-05 add MCU pinouts & add STM .ioc file
    [mcu.kicad_sch, rf.kicad_sch]
2022-08-05 adjust footprints
    [Mini17.kicad_pcb, Mini17.kicad_sch, interface.kicad_sch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]
2022-08-06 move cc1200 spi to spi-5 & update other labels throughout
    [Mini17.kicad_pcb, interface.kicad_sch, mcu.kicad_sch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]
2022-08-06 starting basic layout
    [Mini17.kicad_pcb, rf.kicad_sch]
2022-08-07 rough layout of cc1200
    [Mini17.kicad_pcb, Mini17.kicad_sch, mcu.kicad_sch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]
2022-08-07 fix issue 21 & 20 & move MCU to align w/ grid
    [Mini17.kicad_pcb, Mini17.kicad_sch, mcu.kicad_sch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]
2022-08-07 add pdf schematic
2022-08-07 R7 update
    [Mini17.kicad_sch, audio.kicad_sch, interface.kicad_sch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]
2022-08-07 fixup PTT/Audio (Issue 14), add RGB LED (Issue 26), Connect LEDs to MCU & add them to the .ioc file
    [Mini17.kicad_pcb, Mini17.kicad_sch, audio.kicad_sch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]
2022-08-08 add encoder & volume control, move SD_DET to accommodate encoder
    [Mini17.kicad_sch, interface.kicad_sch, mcu.kicad_sch]
2022-08-08 Minor corrections
    - fixed microphone connection and part values
    - added a few TPs
    - changed C27 footprint
    [Mini17.kicad_sch, audio.kicad_sch, interface.kicad_sch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]
2022-08-08 Schematic update
    - nets for the internal speaker renamed
    - encoder nets renamed, encoder circuit updated
    - various other minor edits
    [Mini17.kicad_sch, audio.kicad_sch, interface.kicad_sch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]
2022-08-08 Additional function buttons - F1, F2
    Closes #24
    [Mini17.kicad_sch, interface.kicad_sch, mcu.kicad_sch]
2022-08-08 Schematic update - PDF render
2022-08-08 Pinout update
    Added `BTN_F1` and `BTN_F2` function buttons
2022-08-10 add fpc display board connector, move components around, rough size of board
    [Mini17.kicad_pcb, Mini17.kicad_sch, audio.kicad_sch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]
2022-08-15 many edits throughout, added board edges for main & HMI combined, added rough layouts for some components on both
    [HMI.kicad_sch, Mini17.kicad_pcb, Mini17.kicad_sch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]
2022-08-15 J3 UART conn change
    Fixes #33
    [Mini17.kicad_sch, audio.kicad_sch, interface.kicad_sch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]
2022-08-16 SPI for keyboard readout, FPC conn update
    [hmi.kicad_sch]
2022-08-16 MCU swap
    [Mini17.kicad_sch, audio.kicad_sch, interface.kicad_sch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]
2022-08-16 Removed RTC
    [Mini17.kicad_sch, audio.kicad_sch, interface.kicad_sch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]
2022-08-17 add HMI J4 and encoder footprints and change encoder schematic
    [hmi.kicad_pcb, hmi.kicad_sch]
2022-08-19 Add ANY_KEY signal from keypad.
    [Mini17.kicad_sch, audio.kicad_sch, hmi.kicad_sch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]
2026-01-30 Update Mini17 description in README.md
    Stalled.
